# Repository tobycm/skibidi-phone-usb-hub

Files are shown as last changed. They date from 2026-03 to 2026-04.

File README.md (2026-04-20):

# skibidi phone usb hub

a very skibidi usb hub for my google pixel 7. powered by the fe1.1s and will power, providing 1 upstream usb c port, 2 downstream usb c ports, and 2 downstream usb a ports!!

[\[Blueprint\]](https://blueprint.hackclub.com/projects/13784) | [\[KiCanvas\]](https://kicanvas.org/?repo=https%3A%2F%2Fgithub.com%2Ftobycm%2Fskibidi-phone-usb-hub%2Ftree%2Fmain%2Fpcb) | [\[Onshape\]](https://cad.onshape.com/documents/10b57464fda6e11087981088/w/324a5dd08e96a242cfbf7cb1/e/a8a34f6420c32109d6a4c98d) | [\[Interactive BOM\]](https://html-preview.github.io/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)

### Update (Mar 21 2026 13:08 PST)

Going to drop the big bulk capacitor as that might cause too much inrush current. Each 10uF at each port should be enough, adds up to 50uF for VBUS.

Updated .step file: removed cutout for bulk capacitor.

## PCB

4 Layer PCB, stackup JLC04161H-7628 from JLCPCB

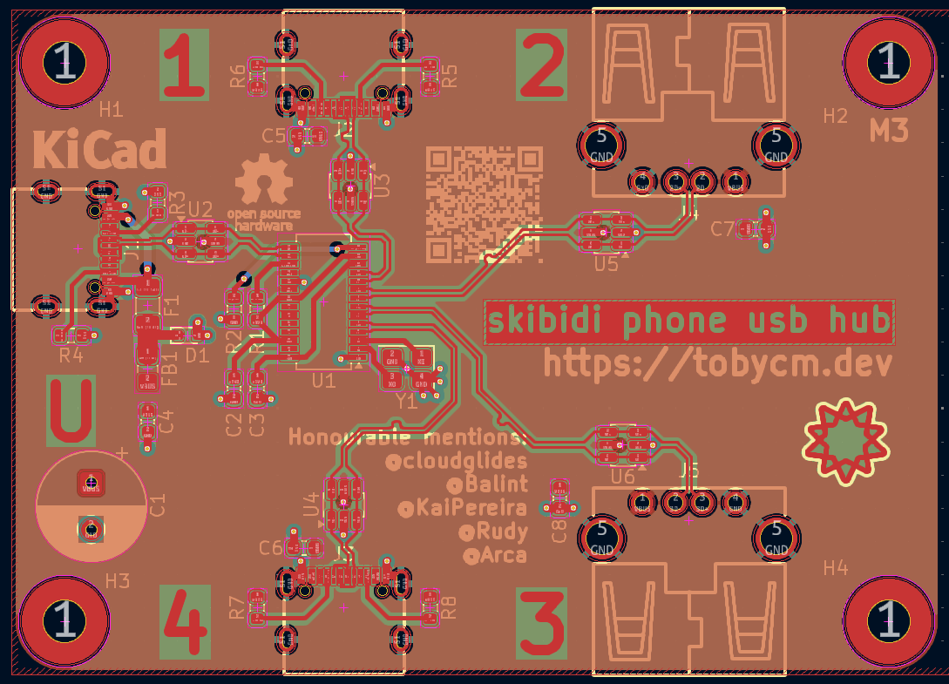
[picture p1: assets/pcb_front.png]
pcb front layer


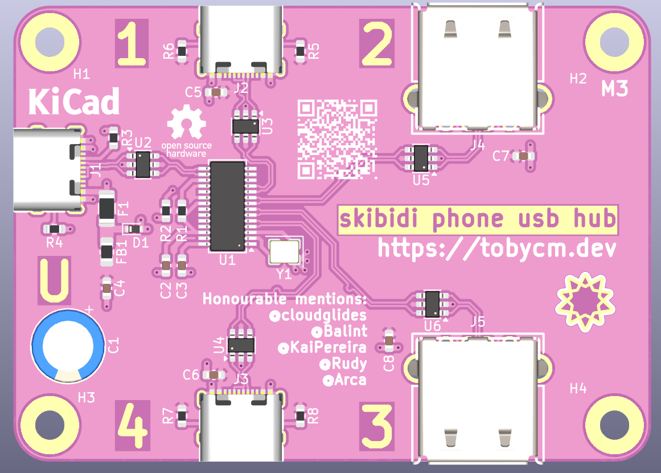
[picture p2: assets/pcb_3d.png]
pcb 3d view


## Schematic

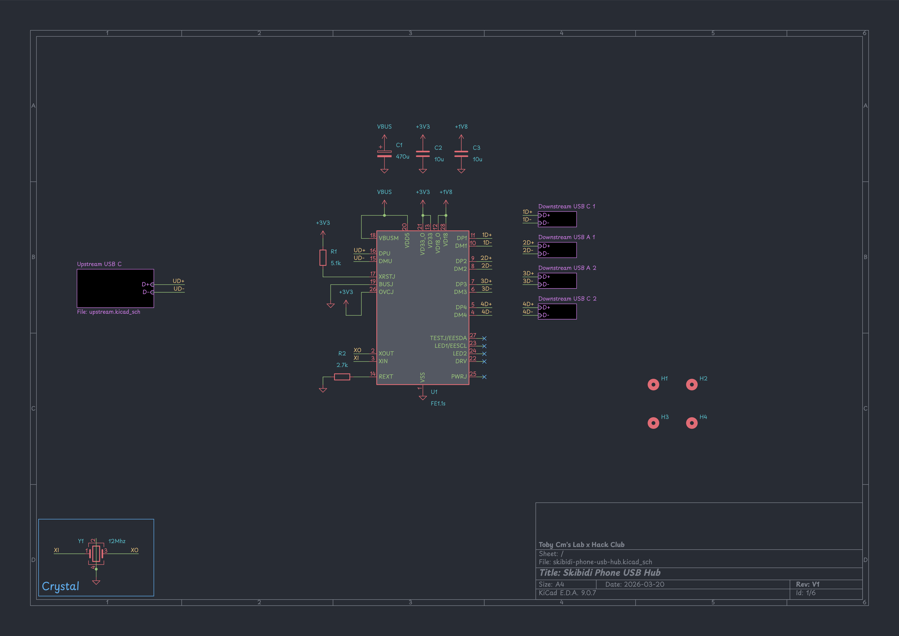
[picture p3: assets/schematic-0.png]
schematic page 1

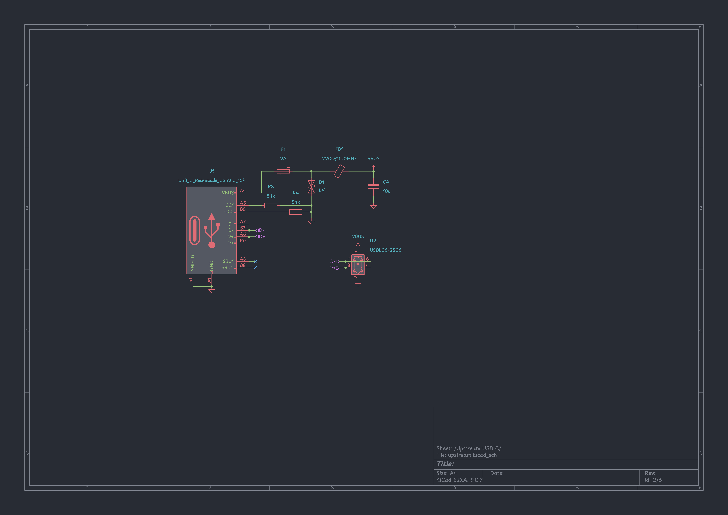
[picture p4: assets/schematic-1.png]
schematic page 2

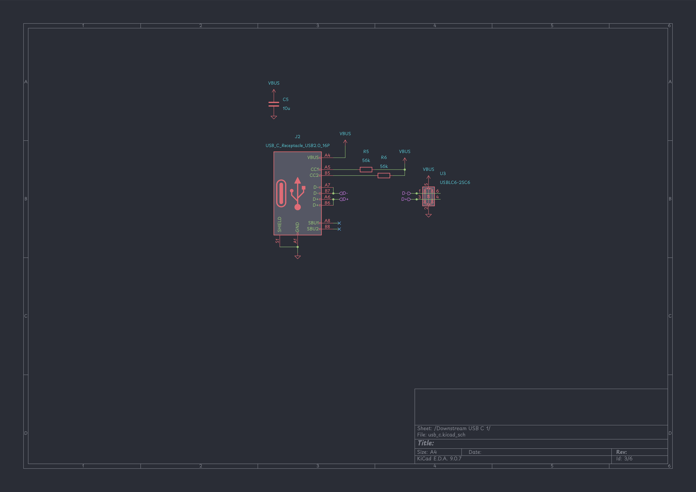
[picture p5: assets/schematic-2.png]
schematic page 3

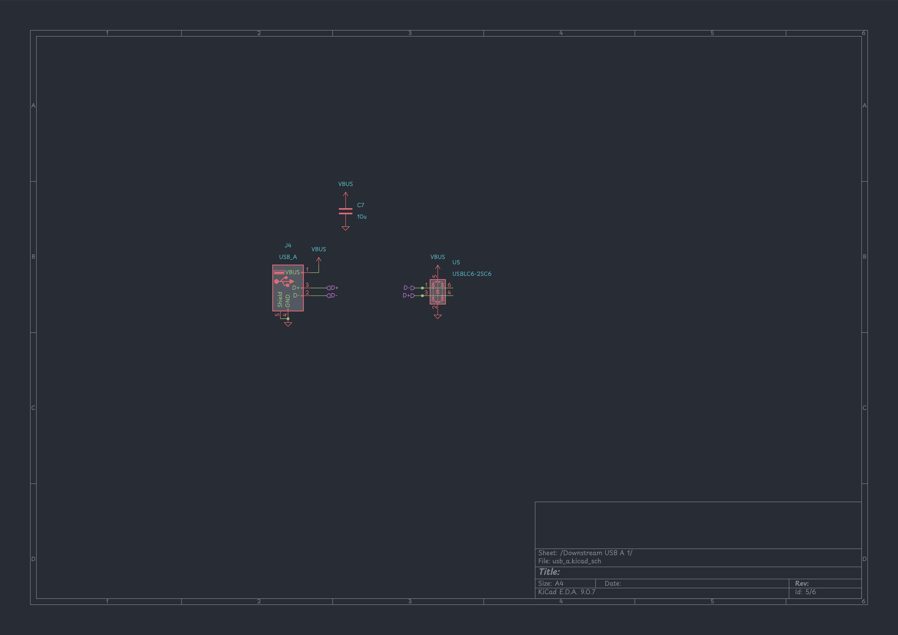
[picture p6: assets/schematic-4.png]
schematic page 5


## CAD

Onshape Model Link: https://cad.onshape.com/documents/10b57464fda6e11087981088/w/324a5dd08e96a242cfbf7cb1/e/a8a34f6420c32109d6a4c98d

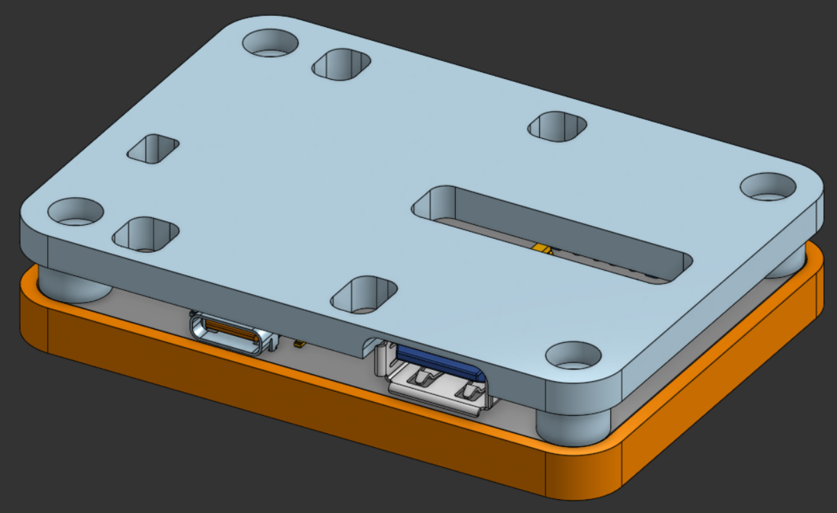
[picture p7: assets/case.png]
case with pcb


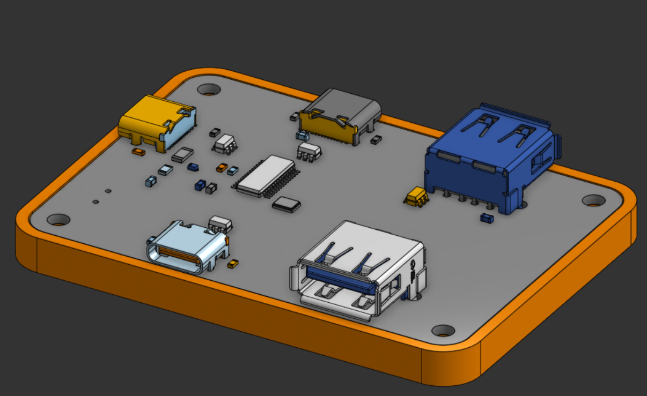
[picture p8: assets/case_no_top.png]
case with no top cover


## BOM

| Description | Quantity | Part # | Unit price | Extended Price USD | Product Link |
| :--- | :--- | :--- | :--- | :--- | :--- |
| 4 USB 2.0 SSOP-28-150mil Interface Controllers RoHS | 10 | FE1.1S-BSOP28BCN | 0.5383 | 5.38 | [Link](https://www.lcsc.com/product-detail/C9359.html) |
| 10uF ±20% 25V Ceramic Capacitor X5R 0603 | 100 | CL10A106MA8NRNC | 0.0176 | 1.76 | [Link](https://www.lcsc.com/product-detail/C96446.html) |
| 2.7kΩ ±1% 100mW 0603 Thick Film Resistor | 100 | FRC0603F2701TS | 0.0011 | 0.11 | [Link](https://www.lcsc.com/product-detail/C2907008.html) |
| Crystal 12MHz ±10ppm 12pF SMD3225-4P | 20 | XL2EL89COI-111YLC-12M | 0.0643 | 1.29 | [Link](https://www.lcsc.com/product-detail/C5280578.html) |
| 5.1kΩ ±1% 100mW 0603 Thick Film Resistor | 100 | FRC0603F5101TS | 0.0012 | 0.12 | [Link](https://www.lcsc.com/product-detail/C2907044.html) |
| 12VC Clamp 6A Ipp ESD DIODE SOT-23-6 | 70 | USBLC6-2SC6 | 0.0403 | 2.82 | [Link](https://www.lcsc.com/product-detail/C2827654.html) |
| USB-A (USB TYPE-A) Receptacle Connector 4 Position Right Angle | 30 | AF 90 WJDG | 0.0471 | 1.41 | [Link](https://www.lcsc.com/product-detail/C456018.html) |
| USB-C (USB TYPE-C) Receptacle Connector 16 Position Surface Mount | 40 | TYPE-C 16PIN 2MD(073) | 0.0617 | 2.47 | [Link](https://www.lcsc.com/product-detail/C2765186.html) |
| 25V 470uF 1.6A@100kHz 20mΩ Aluminum - Polymer Cap | 5 | PH25V470M8X11 | 0.2282 | 1.14 | [Link](https://www.lcsc.com/product-detail/C49232874.html) |
| 56kΩ ±1% 100mW 0603 Thick Film Resistor | 100 | 0603WAF5602T5E | 0.0013 | 0.13 | [Link](https://www.lcsc.com/product-detail/C23206.html) |
| ESD DIODE 5VWM 18.6VC SOD-523 (Owned) | 0 | ESD5Z5.0T1G | 0.0354 | 0 | [Link](https://www.lcsc.com/product-detail/C82044.html) |
| PTC RESET FUSE 12V 2A 1206 (Owned) | 0 | BSMD1206-200-12V | 0.0612 | 0 | [Link](https://www.lcsc.com/product-detail/C883135.html) |
| FERRITE BEAD 220Ω 0805 1LN (Owned) | 0 | BLM21PG221SN1D | 0.023 | 0 | [Link](https://www.lcsc.com/product-detail/C85840.html) |
| LCSC Shipping | 1 | LCSC Shipping | 14.67 | 14.67 | [Link](https://www.lcsc.com/) |
| 4 Layer PCB | 10 | PCB | 2.3 | 23 | [Link](https://jlcpcb.com/) |
| Stencil | 1 | Stencil | 3.05 | 3.05 | [Link](https://jlcpcb.com/) |
| JLCPCB Shipping | 1 | JLCPCB Shipping | 10.08 | 10.08 | [Link](https://jlcpcb.com/) |
| 150pcs Nylon Standoff/Screw Kit | 1 | 1005002059852181 | 4.07 | 4.07 | [Link](https://www.aliexpress.com/item/1005002059852181.html) |
| Aliexpress Shipping | 1 | Aliexpress Shipping | 2.04 | 2.04 | [Link](https://www.aliexpress.com) |
| **Total** | | | | **73.54** | |

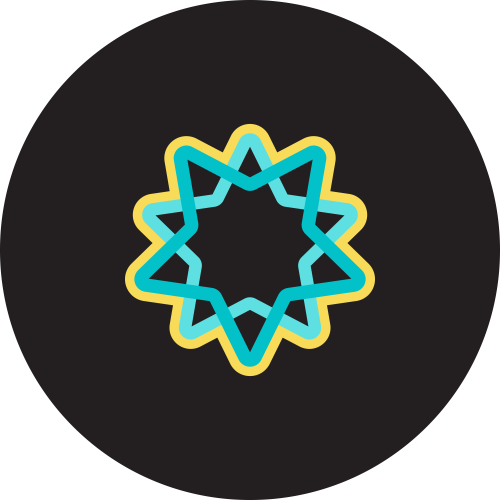
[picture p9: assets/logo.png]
 <a href="https://github.com/tobycm">tobycm</a>

This project was funded by [Blueprint](https://blueprint.hackclub.com/), a grant program by Hack Club that supports open source hardware projects for teenagers.

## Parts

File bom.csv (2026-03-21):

Description | Quantity | Part # | Unit price | Extended Price USD | Product Link
4 USB 2.0 SSOP-28-150mil Interface Controllers RoHS | 10 | FE1.1S-BSOP28BCN | 0.5383 | 5.38 | https://www.lcsc.com/product-detail/C9359.html
10uF ±20% 25V Ceramic Capacitor X5R 0603 | 100 | CL10A106MA8NRNC | 0.0176 | 1.76 | https://www.lcsc.com/product-detail/C96446.html
2.7kΩ ±1% 100mW 0603 Thick Film Resistor | 100 | FRC0603F2701TS | 0.0011 | 0.11 | https://www.lcsc.com/product-detail/C2907008.html
Crystal 12MHz ±10ppm 12pF SMD3225-4P | 20 | XL2EL89COI-111YLC-12M | 0.0643 | 1.29 | https://www.lcsc.com/product-detail/C5280578.html
5.1kΩ ±1% 100mW 0603 Thick Film Resistor | 100 | FRC0603F5101TS | 0.0012 | 0.12 | https://www.lcsc.com/product-detail/C2907044.html
12VC Clamp 6A Ipp ESD DIODE SOT-23-6 | 70 | USBLC6-2SC6 | 0.0403 | 2.82 | https://www.lcsc.com/product-detail/C2827654.html
USB-A (USB TYPE-A) Receptacle Connector 4 Position Right Angle | 30 | AF 90 WJDG | 0.0471 | 1.41 | https://www.lcsc.com/product-detail/C456018.html
USB-C (USB TYPE-C) Receptacle Connector 16 Position Surface Mount, Right Angle | 40 | TYPE-C 16PIN 2MD(073) | 0.0617 | 2.47 | https://www.lcsc.com/product-detail/C2765186.html
25V 470uF 1.6A@100kHz 20mΩ@100kHz ±20% Through Hole,D8xL11.5mm Aluminum - Polymer Capacitors RoHS | 5 | PH25V470M8X11 | 0.2282 | 1.14 | https://www.lcsc.com/product-detail/C49232874.html
56kΩ ±1% 100mW 0603 Thick Film Resistor | 100 | 0603WAF5602T5E | 0.0013 | 0.13 | https://www.lcsc.com/product-detail/C23206.html
ESD DIODE 5VWM 18.6VC SOD-523 (already have) | 0 | ESD5Z5.0T1G | 0.0354 | 0 | https://www.lcsc.com/product-detail/C82044.html
PTC RESET FUSE 12V 2A 1206 (already have) | 0 | BSMD1206-200-12V | 0.0612 | 0 | https://www.lcsc.com/product-detail/C883135.html
FERRITE BEAD 220Ω 0805 1LN (already have) | 0 | BLM21PG221SN1D | 0.023 | 0 | https://www.lcsc.com/product-detail/C85840.html
LCSC Shipping | 1 | LCSC Shipping | 14.67 | 14.67 | https://www.lcsc.com/
4 Layer PCB | 10 | PCB | 2.3 | 23 | https://jlcpcb.com/
Stencil | 1 | Stencil | 3.05 | 3.05 | https://jlcpcb.com/
JLCPCB Shipping | 1 | JLCPCB Shipping | 10.08 | 10.08 | https://jlcpcb.com/
150pcs White Nylon Hex Screw M2 M2.5 M3 M4 M5 Bolt Nut Standoff Spacer Kit with Plastic Box Corrosion Resistant | 1 | 1005002059852181 | 4.07 | 4.07 | https://www.aliexpress.com/item/1005002059852181.html
Aliexpress Shipping | 1 | Aliexpress Shipping | 2.04 | 2.04 | https://www.aliexpress.com
 |  | Total: |  | 73.54

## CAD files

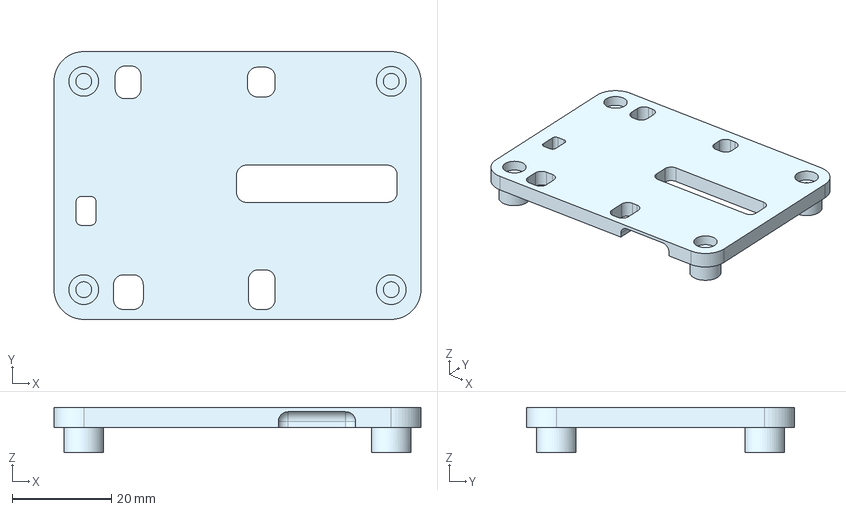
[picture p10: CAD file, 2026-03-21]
cad/skibidi phone usb hub case - Top Cover.step
74.0 x 54.0 x 9.09 mm

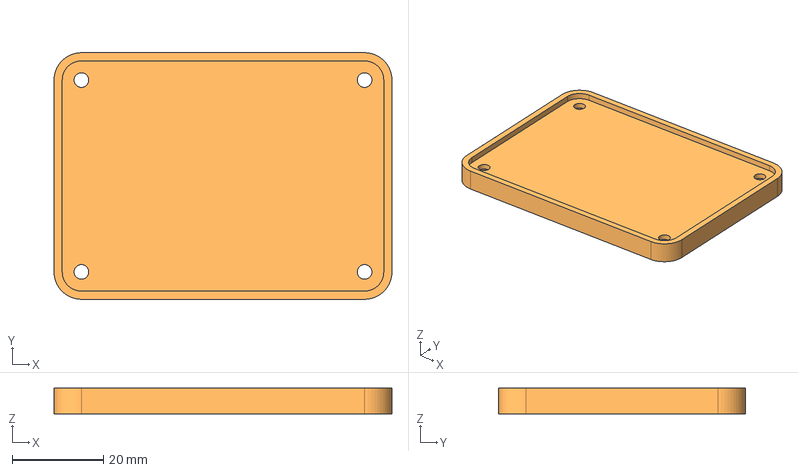
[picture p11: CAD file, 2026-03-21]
cad/skibidi phone usb hub case - Bottom Cover.step
74.0 x 54.0 x 5.60 mm

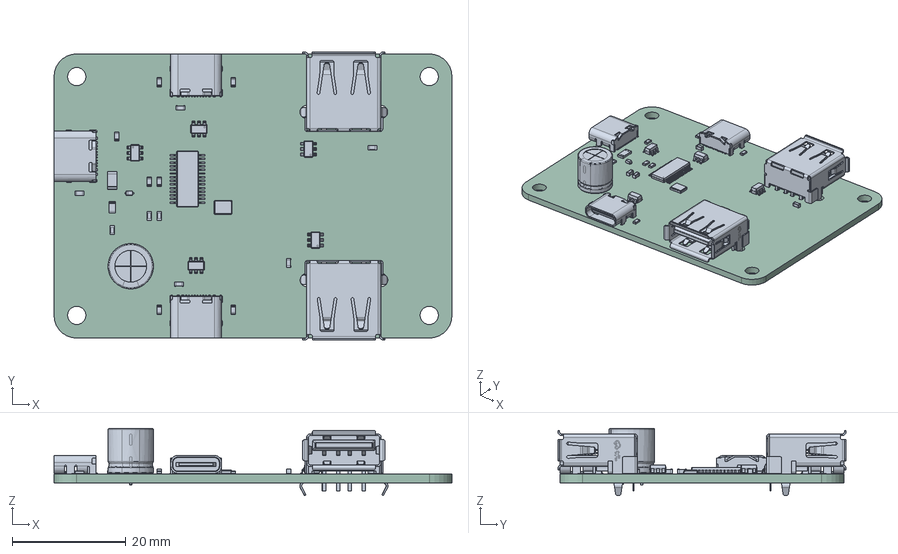
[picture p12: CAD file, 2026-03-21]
cad/skibidi-phone-usb-hub.step
70.0 x 50.7 x 11.9 mm
C_0603_1608Metric x 7
SOT-23-6 x 5
R_0603_1608Metric x 8
CP_Radial_D8.0mm_P3.50mm
USB-C-SMD_TYPE-C-6PIN-2MD-073 x 3
D_SOD-523
Crystal_SMD_3225-4Pin_3.2x2.5mm
USB-A-TH_4P-L14.5-W14.0-H7.6-S2.71 x 2
R_0805_2012Metric
Fuse_1206_3216Metric
SSOP-28_3.9x9.9mm_P0.635mm
skibidi-phone-usb-hub_PCB

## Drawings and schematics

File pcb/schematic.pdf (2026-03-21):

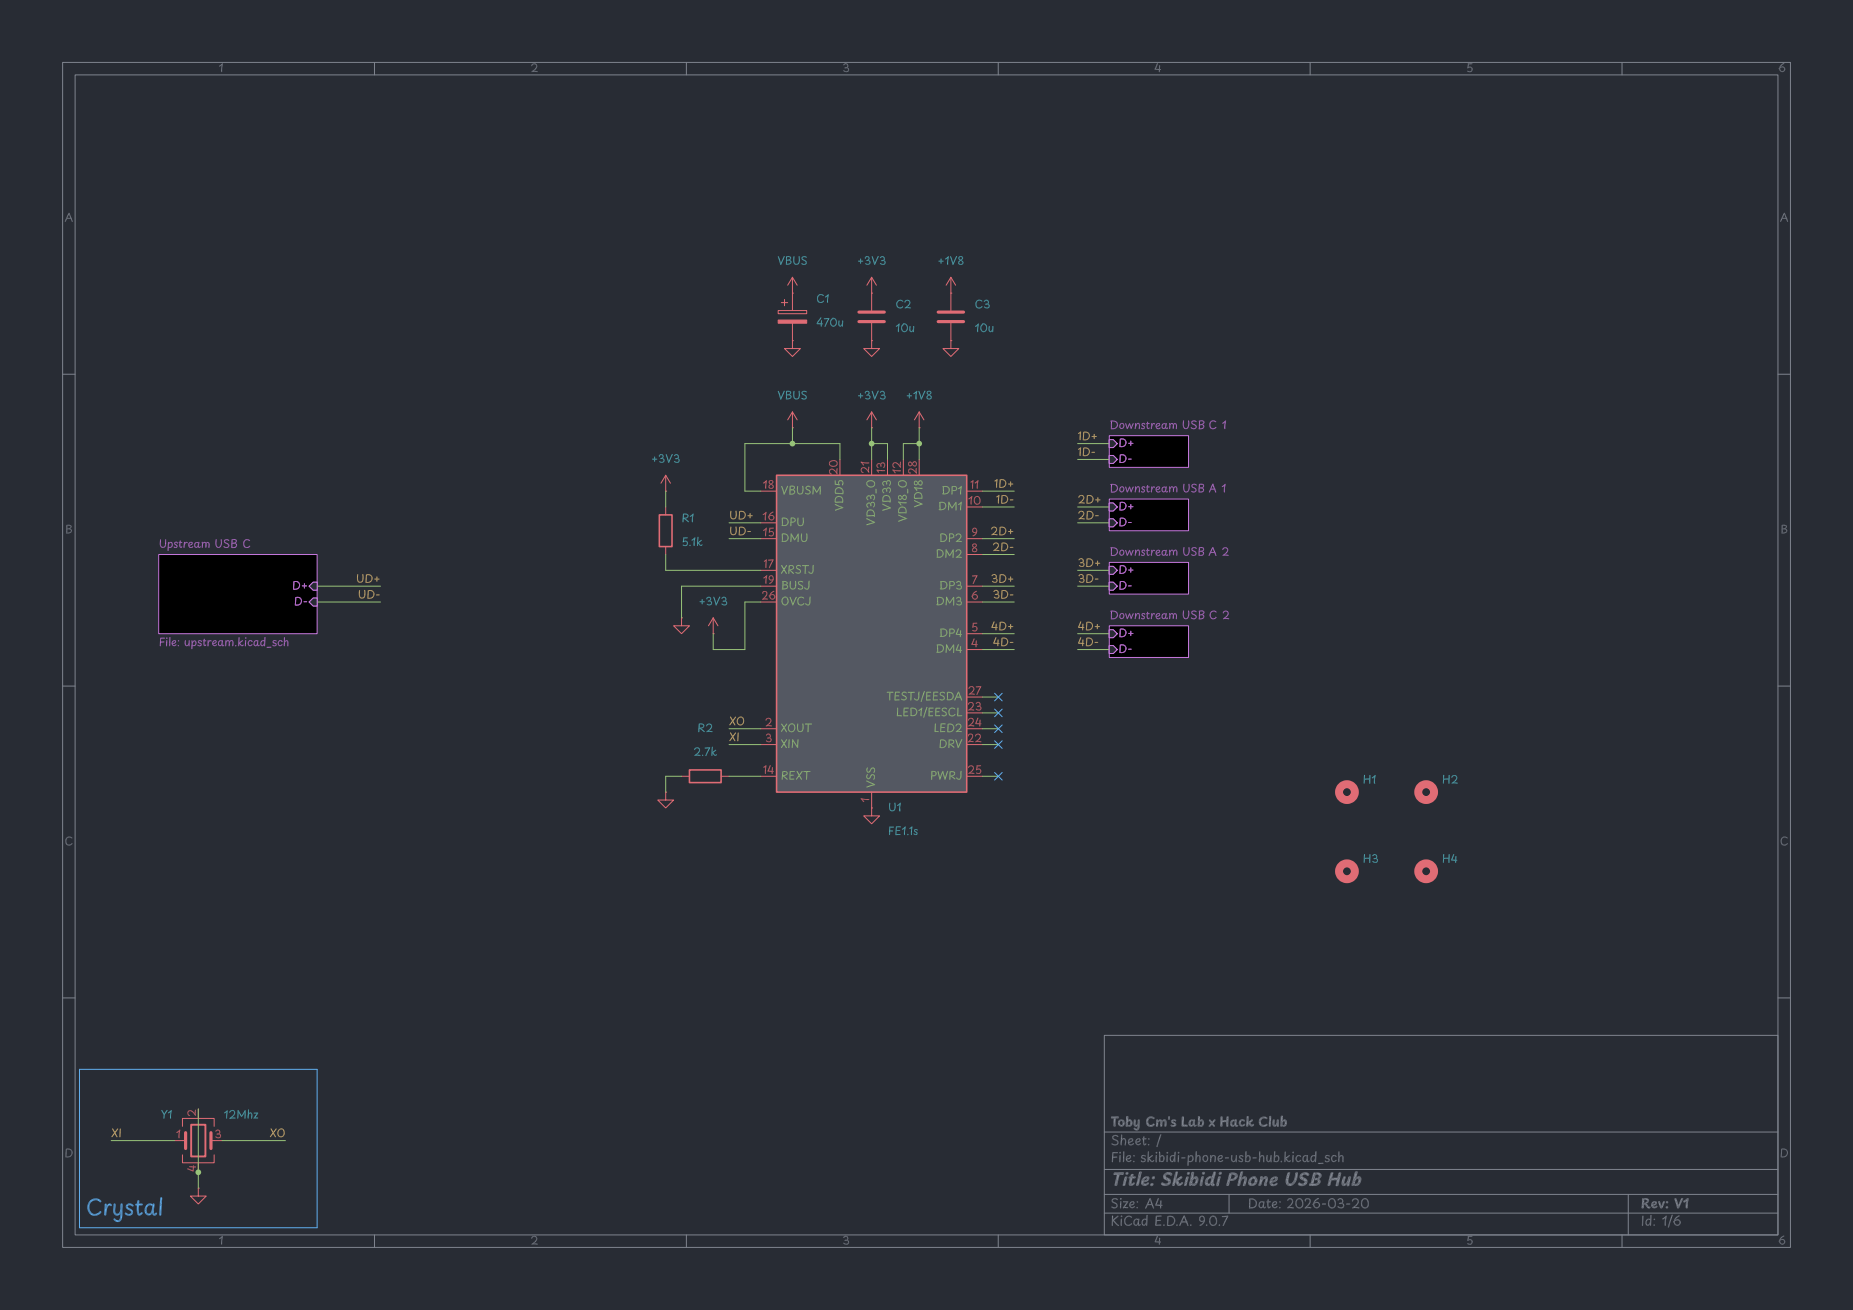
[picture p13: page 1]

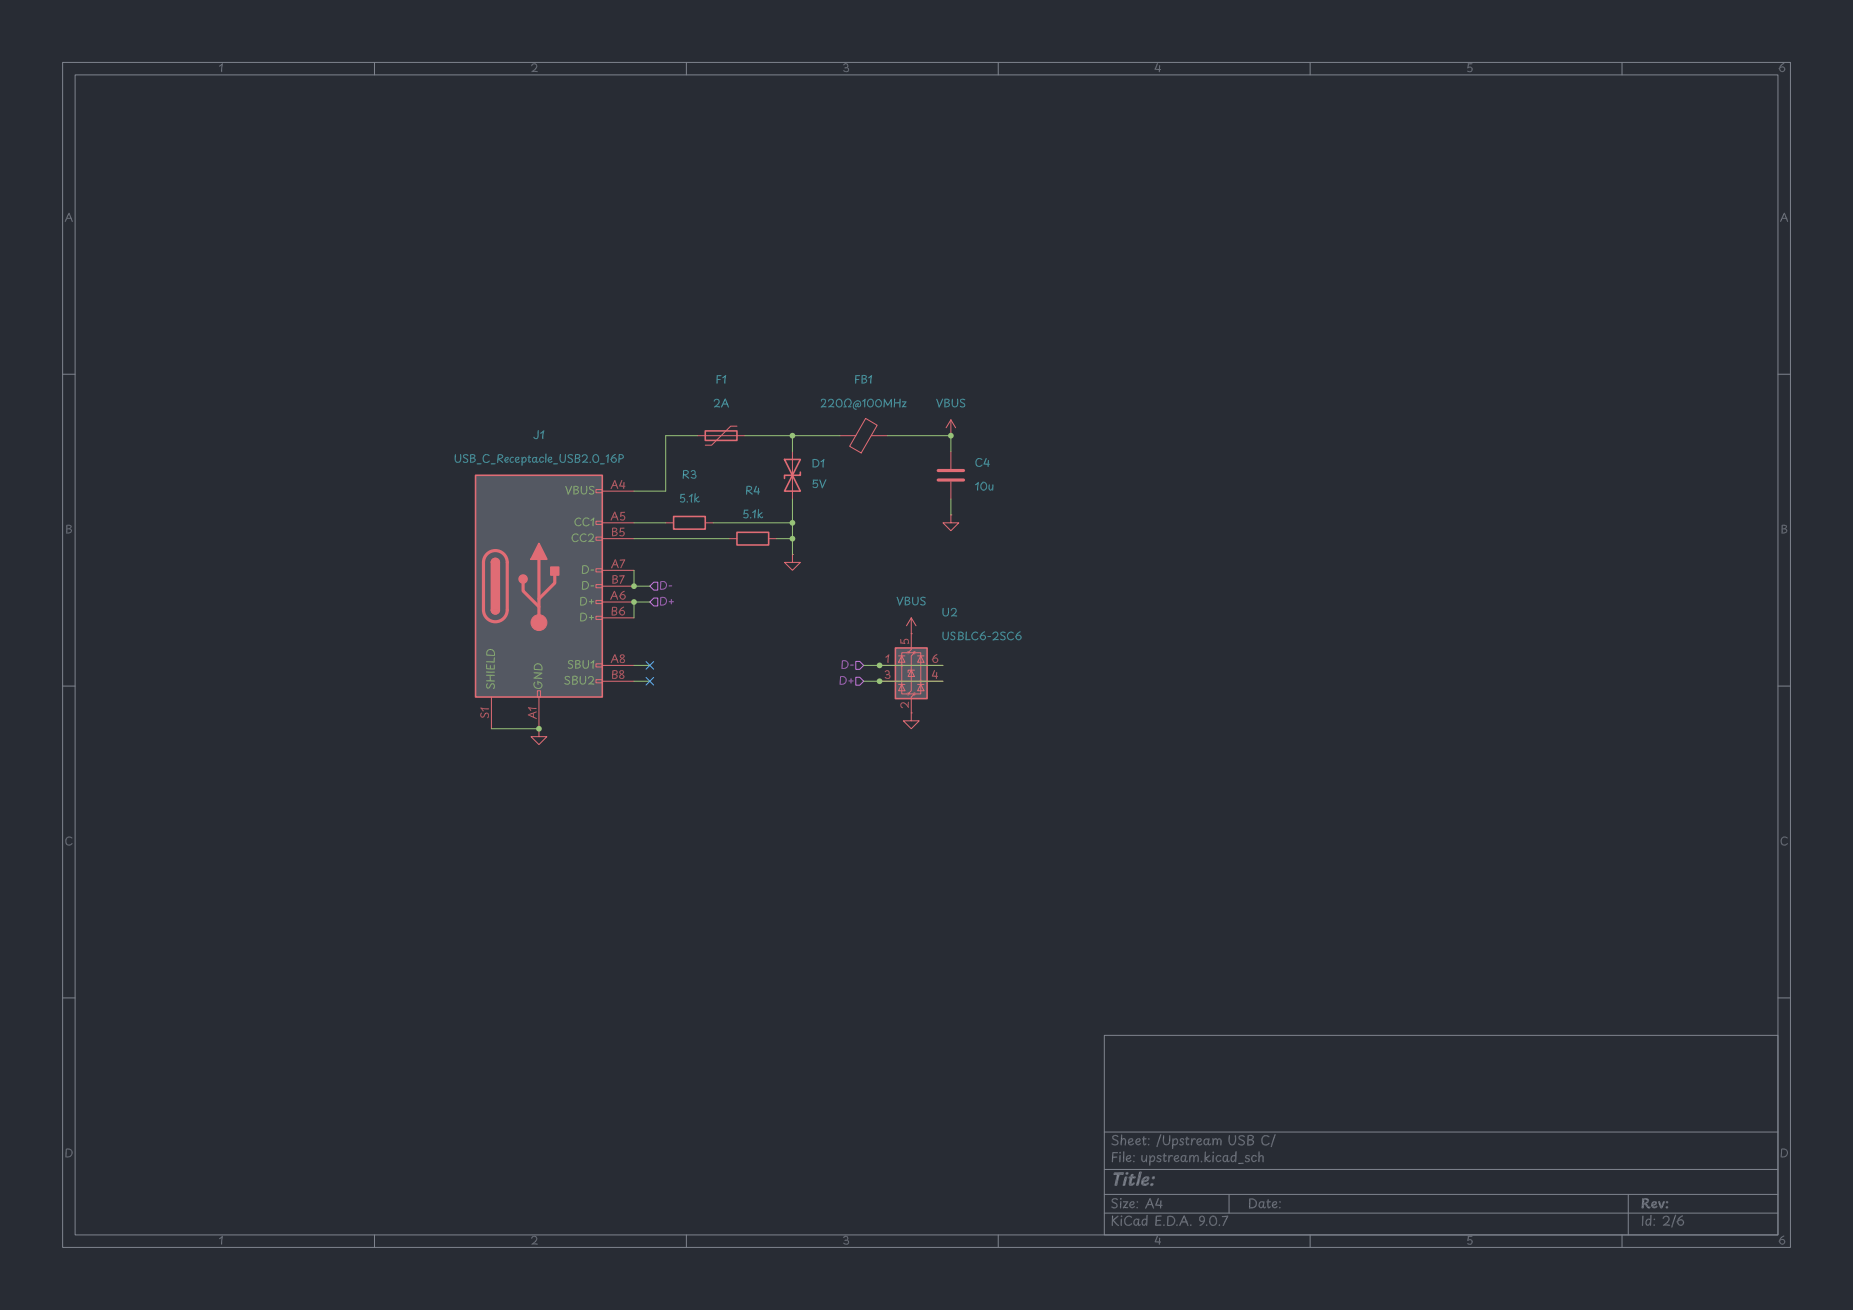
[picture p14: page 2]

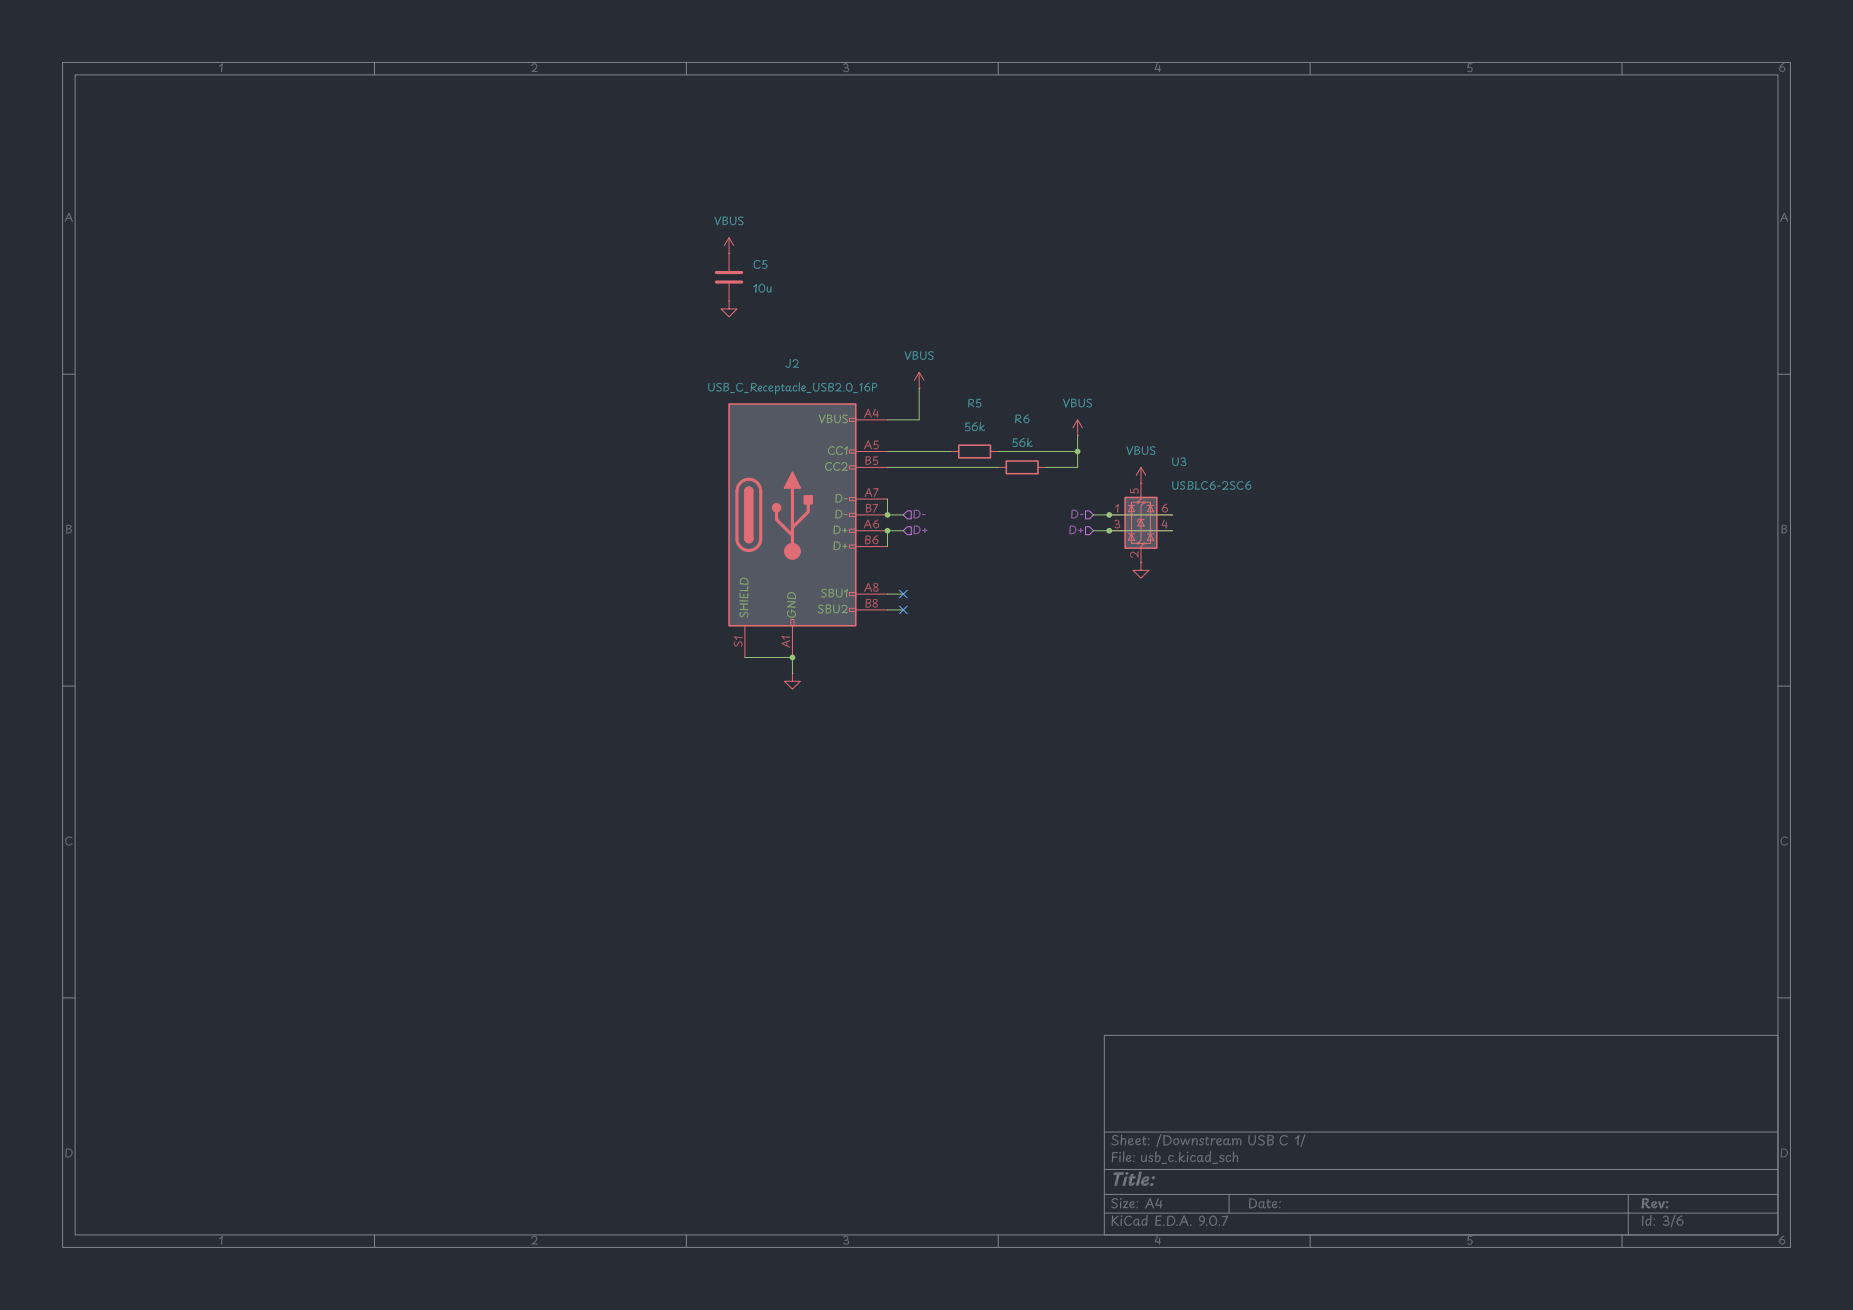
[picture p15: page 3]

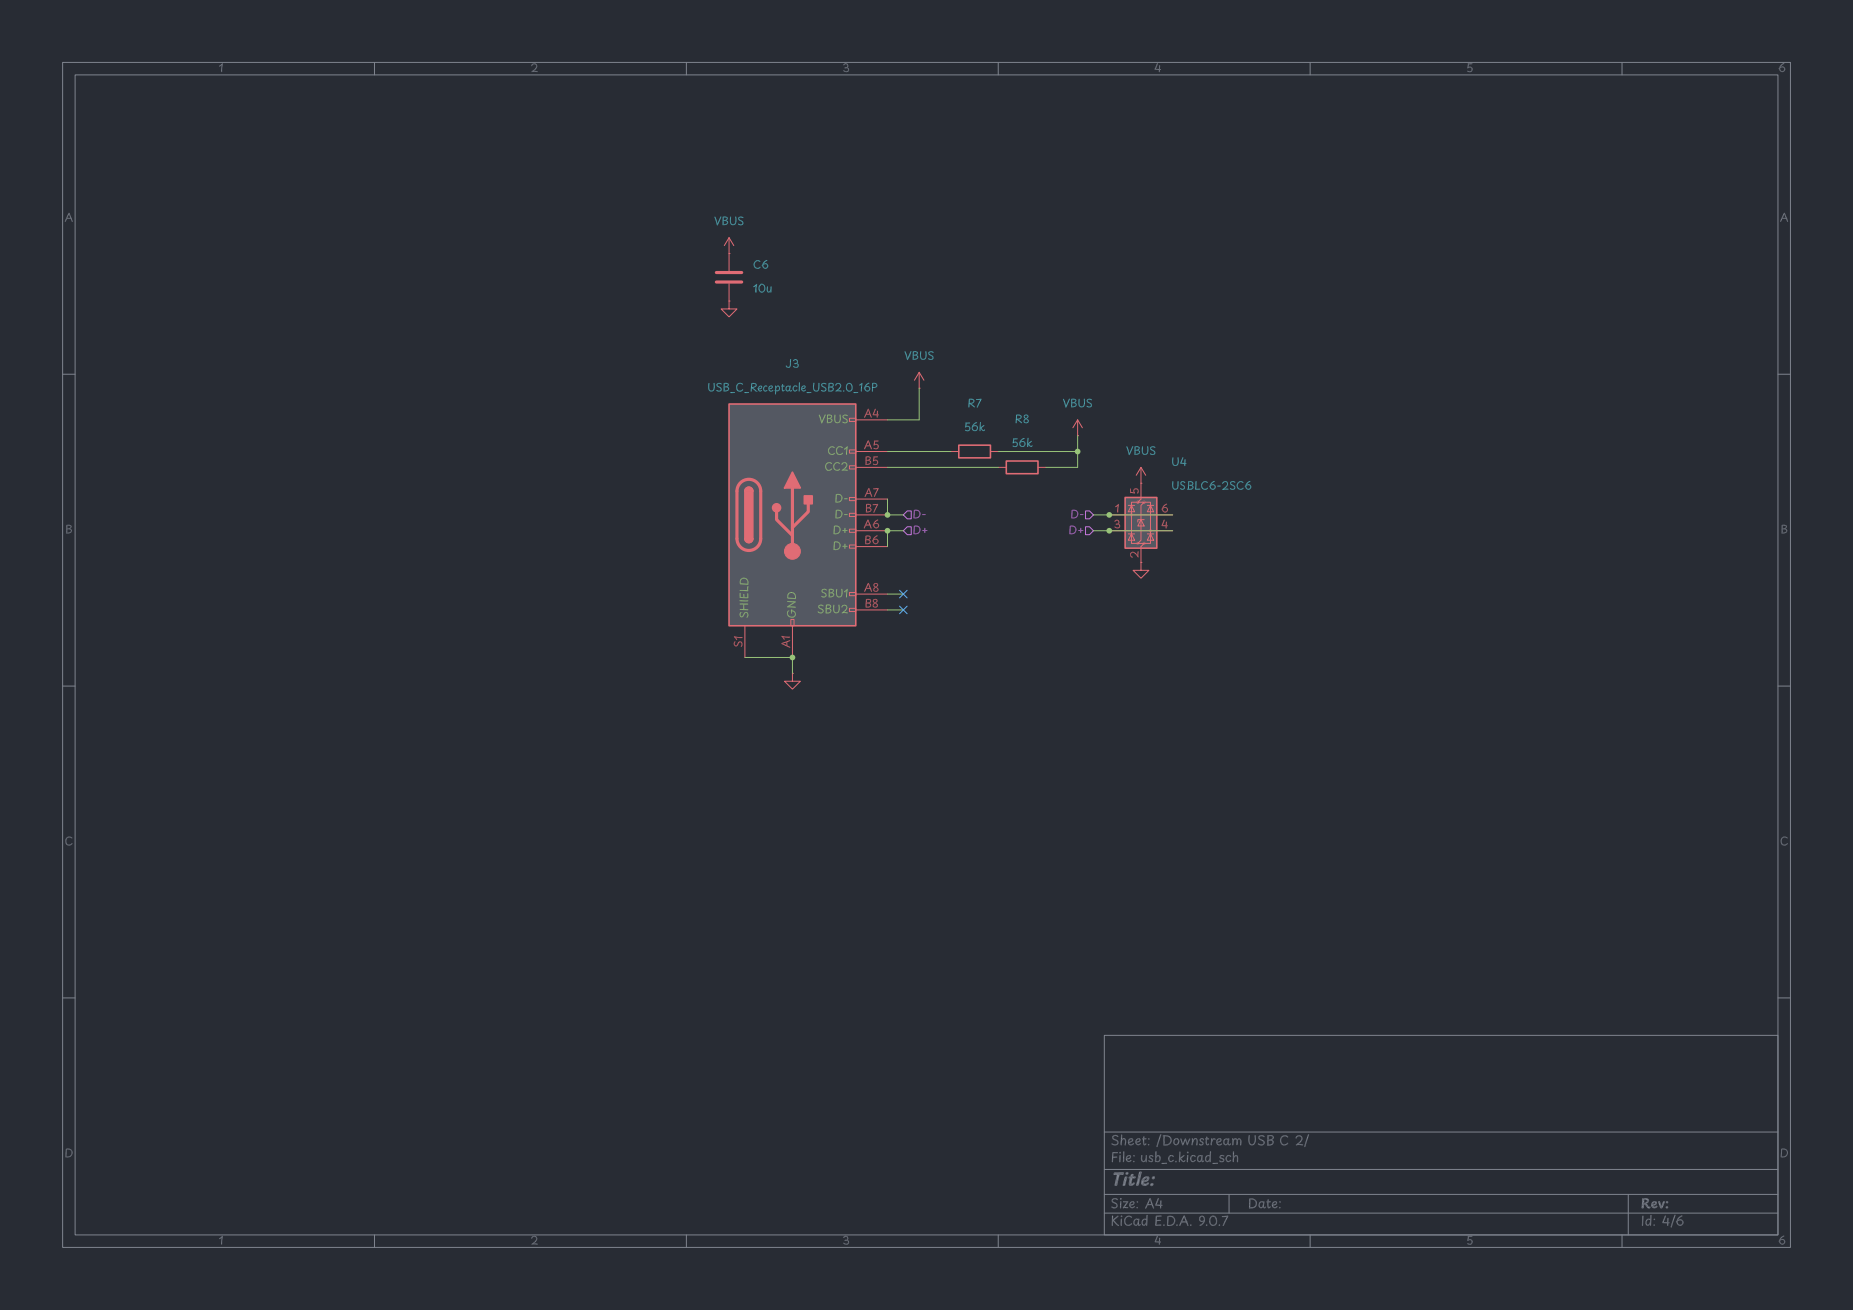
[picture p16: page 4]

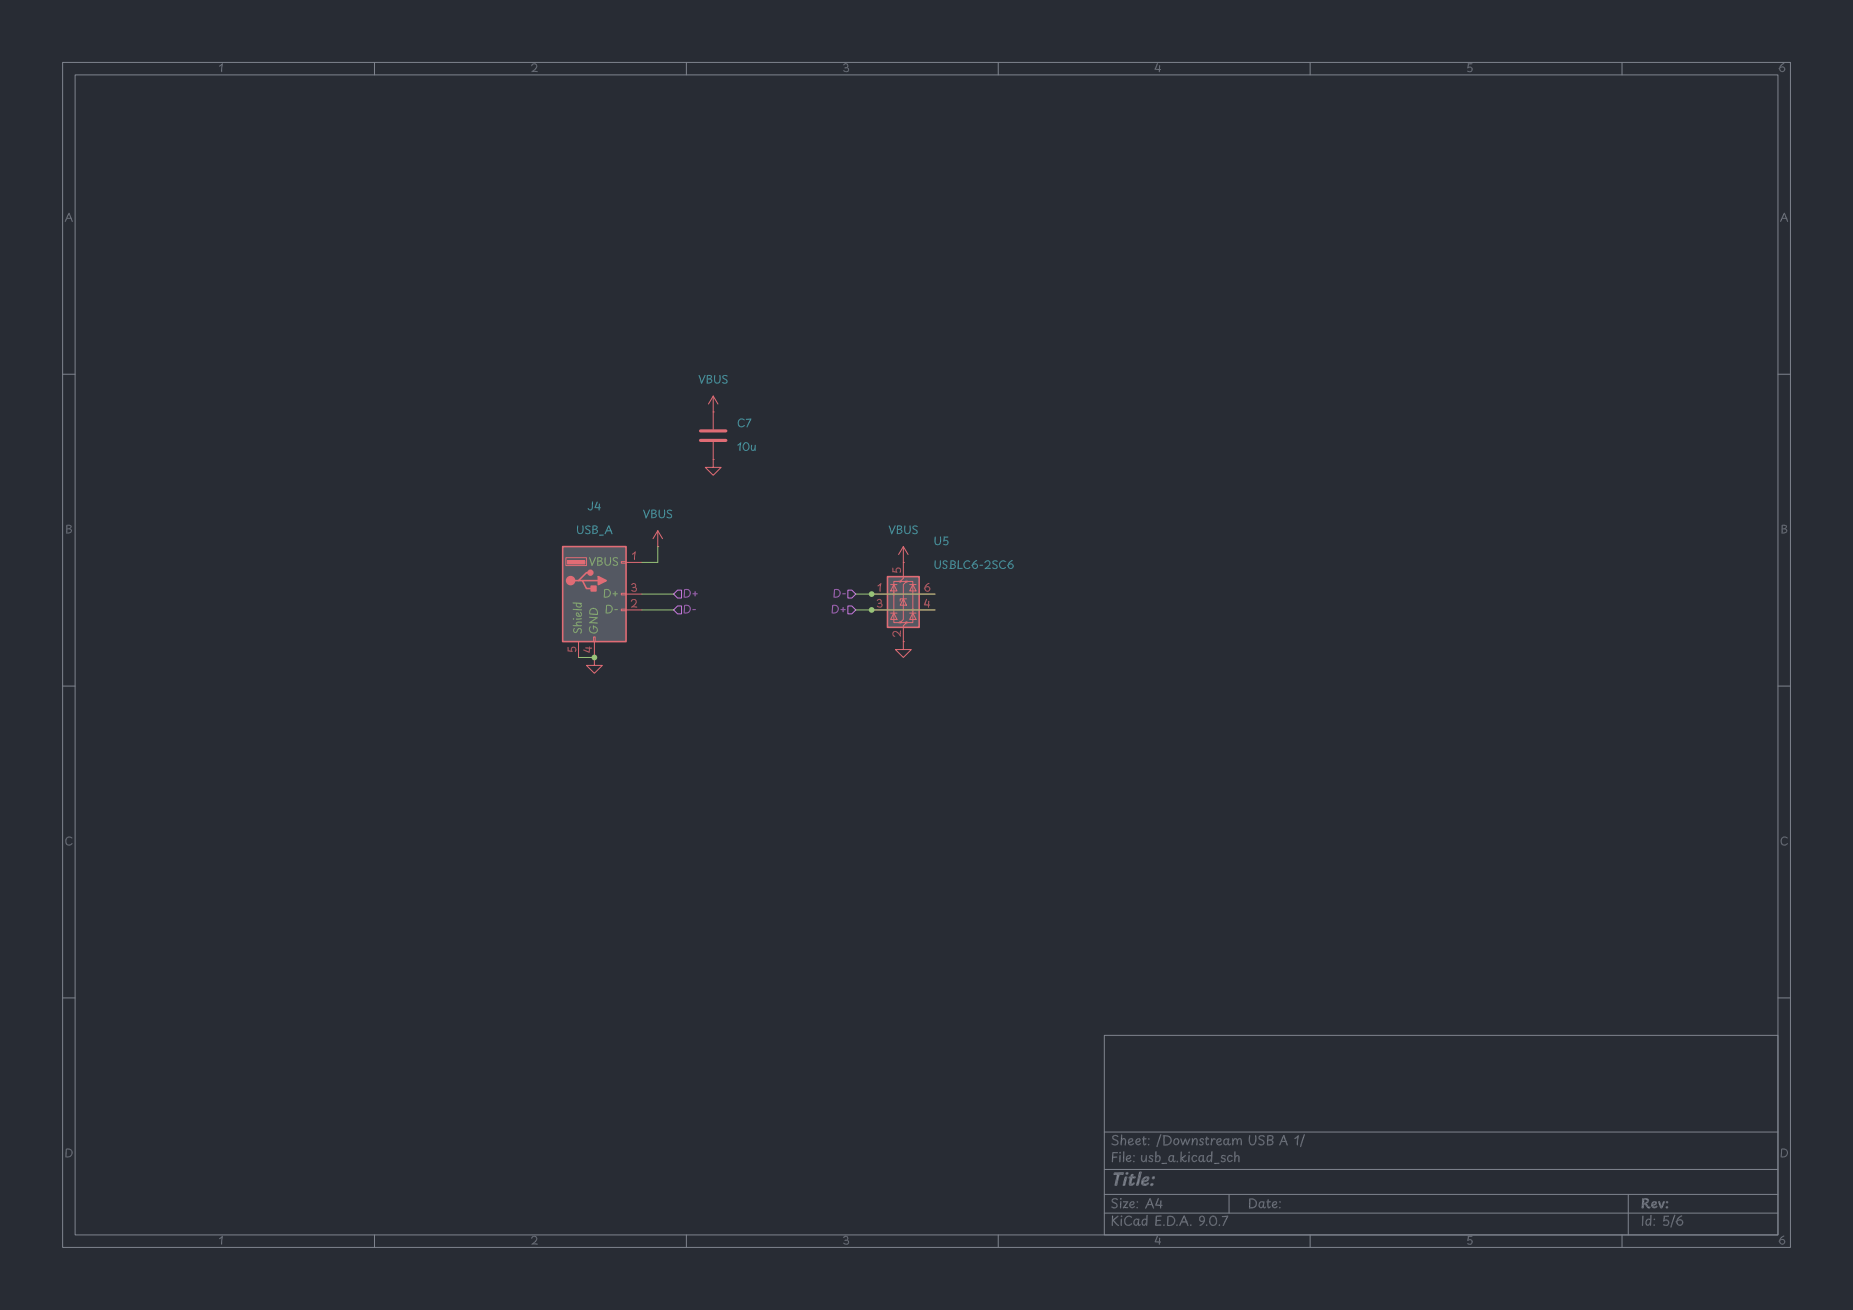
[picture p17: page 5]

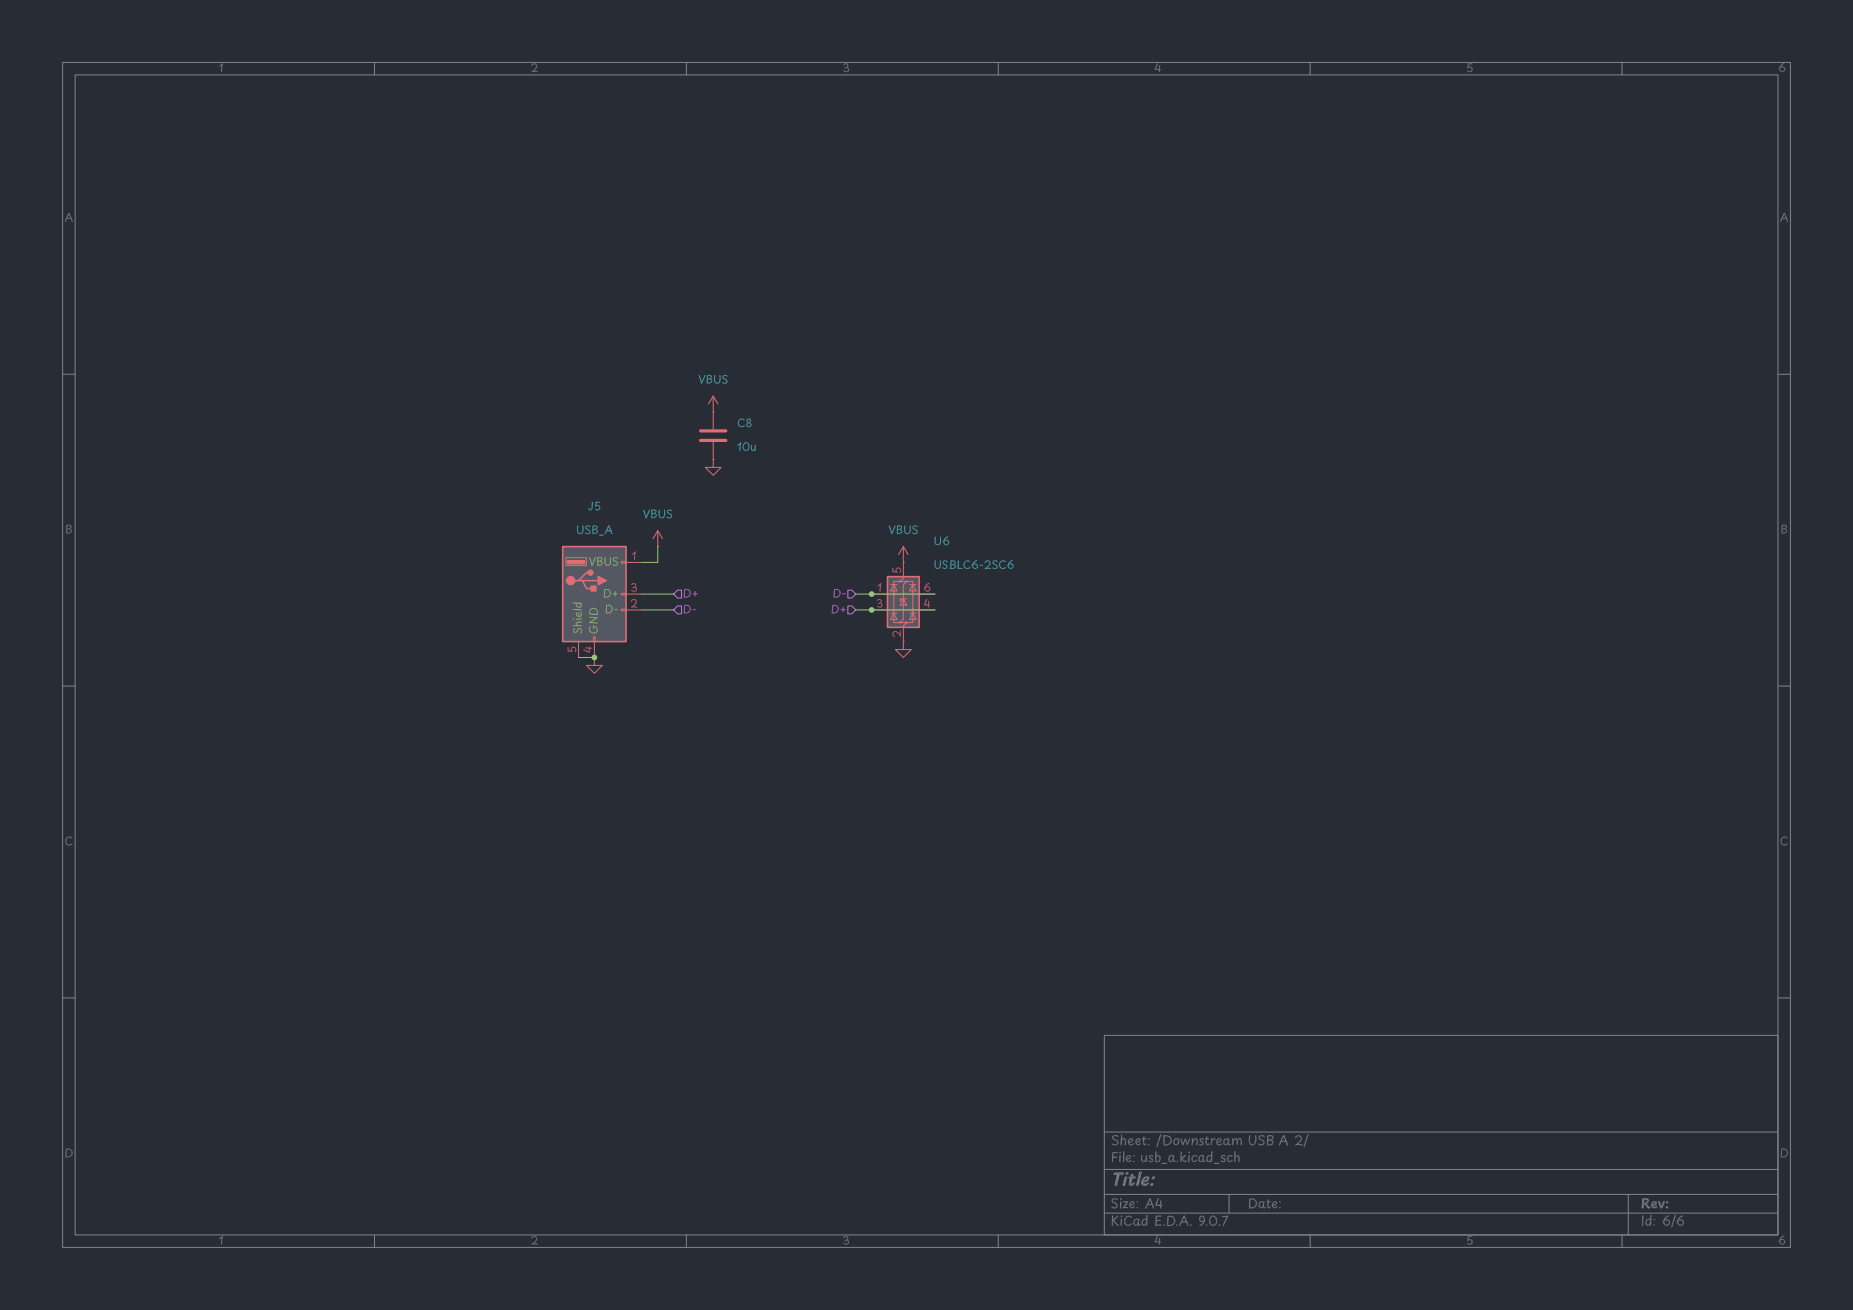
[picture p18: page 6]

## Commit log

2026-03-21 pcb and bom and readme
    [BOM-skibidi-phone-usb-hub.csv, bom.csv, skibidi-phone-usb-hub.csv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]
2026-03-21 add pcb step
    [skibidi-phone-usb-hub.csv, skibidi-phone-usb-hub.step]
2026-03-21 add BOM to readme
2026-03-21 add case models + readme renders
    [skibidi phone usb hub case - Bottom Cover.step, skibidi phone usb hub case - Top Cover.step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]
2026-03-21 update bom with screws, remove bulk capacitor
    [bom.csv, skibidi phone usb hub case - Bottom Cover.step, skibidi phone usb hub case - Top Cover.step]
2026-03-21 add schematic pdf + metadata
    [skibidi-phone-usb-hub.kicad_sch]
2026-03-22 update pcb fill zone, add schematic images and update case image in readme
2026-04-20 add ibom and fixes issue with power negotiation
    [BOM-skibidi-phone-usb-hub.csv, skibidi-phone-usb-hub.kicad_sch, upstream.kicad_sch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]
